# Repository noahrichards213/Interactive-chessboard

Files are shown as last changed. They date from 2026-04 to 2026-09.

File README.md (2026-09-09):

# Interactive chessboard

LED-Guided Smart Chessboard
An interactive, LED-guided smart chessboard designed for beginners. The board uses magnetic piece tracking via Hall effect sensors, provides real-time visual move guidance through an integrated LED matrix, all run by a chess engine powered by an ESP32.

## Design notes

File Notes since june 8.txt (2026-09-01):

Priority #1: get the MCP23S17 working

	ECE 231 concepts! how to calculate the current through the resistor LED combo
	0. (note cannot use OHM's law b/c diode isn't a resistor, must use datasheet current-voltage characteristic)
	1. If = (3.3 - Vf)/R, where If and Rf are forward current and forward voltage
 	2. Guess a correct point on graph
	3. According to the datasheet for the LED we are using:
	@ 1.9V, there is 7mA
        @ 1.95V, there is 15mA

	From my resistor equation:
        @ 1.9V, there is 9.3mA
	@ 1.95V, there is 9mA

	Therefore, the real operating point is somewhere between 1.9 and 1.95V and 7mA and 15mA

	So, we were outputting at most 15mA current out of each pin, 8 times per MCP, which is 5 * 15mA = 120mA < 125mA limit.

	So, it is not possible that the MCP is actually damaged from this (even w/ resistor tolerance the range we created is just too big!! There is another problem

Possible problems
1. SPI not connecting
	test: use the who am i function (use exact same code as the gyro, very very carefully read MCP datasheet for source code)
	another test: test using purposely wrongly defined pins and see if MCP.begin stil works. if it still does, then spi may not be connectinat all

June 10:

We have gotten the MCP working. Let us ponder this problem. It seems that all the hall effects have been fried because they only pull up to 0.6. I replaced one and it pulls up to 3.3.

We will need to replace other hall effects and test that (tomorrow). Today we will consider if it is even possible that hall effects were fried.

But how?

We note from the datasheet that the maximum reverse output voltage is 0.5V. We surely exceeded this when testing and trying to write 3.3V into the hall effect pin

So, we must:
- replace all 15 of the fried hall effects
- resolder the broken LED
- frankestein a 5k resistor to the square that is missing one

Then we can start testing our firmware. Start w/ same handwritten code, and then try to implement the whole thign

June 17:
After much testing, i have NO idea why the voltage only pulls up to 0.6. We have two options

- amplify the 0.6 to 3.3 so the MCP can detect it
- try a different Hall effect sensor
- use an analog to digital converter to read it

June 20:
We could use ADC multixplexers. The drawback w/ multiplexers is that we can only recognize one input at a time. Let's think about this, is this okay?

We could poll all the inputs.

Therefore, it is okay! We don't even need a new PCB because the CD74HCx4067 multiplexer takes only the following inputs:
- power
- ground
- enable
- output to an ADC pin on microcontroller
- output to select pins on microcontroller

which we can Frankenstein easily enough

Note: the multiplexer device has a maxmimum source/sink current of 25mA. How do we control for that.\
Solution: recall the functionality of the open drain device. When enough gate voltage is applied, device is shorted, no current. When not enough gate voltage is applied, current determined by pullup resistor. If we use 5kohms, then 3.3V/5kohms = 0.66mA, far less than limit

June 21:
We have ordered the multiplexers. In the meantime, we shall think about the actual final design.

I don't believe there are any suitable 8x8 matrices. So we will try to use a 5mmx5mm LED: https://www.digikey.ca/en/products/detail/quelighting-corp/QLSP08RGB-B/15848745

How will we construct the actual board around the PCB? We need to use headers to bring out hall effects, but that's it. All else should be hidden. LEDS should shine beneath the wood

We should use my glass chessboard so that LED can shine through it?

Because hall effects are kind of weak from distance. I will take the thinnest wood I can buy and make a sort of mask.

June 24:
we have successfully soldered new esp on new board. the following is the minimum we need to Frankenstein in order to test the mux:
select signal (x4)
power (attach another capacitor)
ground (attach another capacitor)
common output (can use GPIO 15, confirmed ADC)
enable signal (tied to ground)
input signal (x2)

Regular solder the hall effect, pullup resistor and decoupling capacitor

10 Frankenstein's total

June 29:
To reduce the number of Frankensteins, we will ground three of the select signals and keep one for testing different channels

The one that is not soldered to ground is s0. When s0 is ON, channel is 1, when s0 is OFF, channel is 0.

July 2:

successfully tested them mux, also retested the MCP. problem with the MCP: we will need 4 on one spi line, but all four will need to communicate at the same (light up leds). how will we accomplish this

July 2 (night):
We are trying to test two MCP's on the same SPI, right now only one of them is working.

First, let's test just the not working one to see if all the PCB connections are correct.

If that is working, then let's reconfigure the SPI. Delete the CS_pin from the argument and see what happens

July 5. 
Unfortuatnely, we can't use MCP's I realized b/c the current draw is far too much (b/c we have 16 LEDS per IC). We need some kind of LED driver

Another problem is that the MCP output just isn't working, which is super frustrating. Randomly stopped working

July 8.
So, we don't actually need the MCP. We have a design that will work for the hall effects, now we need one for the LEDS:
Let's consider the gate driver IC:

Input: weak logic signals (like from ESP 32)
Output: High current & current voltage signals

The kind of gate driver IC we will need depends on the amount of current we will need. let's consider which LED we will use

We are considering this one: JB5630AWT-P-H30GA0000-NZ000001, that is large enough and has the test current of 65mA

I'm liking the TPIC6C595 Power Logic 8-Bit Shift Register, which has:
- 8 outputs (for LEDS) (so we need 8 of them)
- one reset button (can have common for each IC)
- active low output enable
- ground
- shift register clock (can have common for each IC)
- update register clock (can have common for each IC)

Note the max ratings: Continuous drain current, each output, all outputs on, TC = 25°C is 100mA, which is well above the 65mA which will be going through the LED (note we will have compute resistor values precisely that we get the correct voltage LED, which is 2.8V

Here's the test we will perform: cascade two TCP and connect a few LEDS making sure to cover both TCPs
	
July 14.
We need a very low resistance for the LEDS.
Operating point is (2.8V, 65mA).

So, 65mA = (5 - 2.8V)/R, R is about 30 ohms

July 16.
Changing LED source to 3.3V for simplicity of PCB,
and if we choose an R of 10, operating point is at about (2.76V, 54mA), which is about 75% relative luminous flux

July 16 night
We need a switching regulator to 3.3V. So the plan is linear from 7.4 to 5 (use headers to for lipo input output), then switching from 5 to 3.3.

July 17
We need a battery with enough ampere hours, but those all have Deans T headers
We can't have a Deans T receptacle of the PCB (too much mechanical stress), so we need a Deans T to xt30 adapater(xt30 instead of jst because it has the adequate current rating)

July 19

Checking to see if LED driver will get too hot:
- assuming room temparture
- upper bound for current drawn is 60mA

Note that the allowable power dissipated is given by:(Junction temp - Ambient temp)/thermal resistance (variation of Ohm's law)

So, according to datasheet, P = (150-25)/82.3  (SOIC thermal resistance) = lower bound of 1.5 Watts.

How much power is dissipated if we have all 8 LED's on at once?
Upper bound of 60mA squared * 30ohms = 0.11W * 8 < 1 Watt

Also note: the 60mA is not being drawn from 5V because it's an open drain output, it sinks current from the LED voltage source
00
Ensuring that the buck regulator is able to provide enough current (recommended limit is 2A).
Max number of LED's on at once is 27. 60mA * 27 + 500mA for ESP < 2A.

Suppose we use 12 ohm resistor instead: then operating point is at an upper bound of 45mA via Desmos, which is about 60 percent relative luminuous flux. Okay for now

So 45mA * 27 + 500mA = 1.7A + 64 * 0.0045 (from hall effects) is just barely over 2, it's okay

Aug 30

things to add in code
-capturing (which requires changing colour each turn)
-castling
-en passant
-promotion
-weird combinations of these

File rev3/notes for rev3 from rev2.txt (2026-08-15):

July 25
- make LED footprints have more space between anode and cathode, rn it's a tough solder

August 3
- make 7.4 and GND breakouts instead of 5V and GND (into buck converter) (done
- make the breakouts female
- add switch to turn off power 

August 9
- switch not necessary, i need to take out battery to charge anyway
- female breakouts not necessary, if need be i can just solder wires to through holes

- 7.4 breakout done
- LED footprint enlarge done

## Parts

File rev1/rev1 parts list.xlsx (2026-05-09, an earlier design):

Part | # of units | Link | Notes
0.1uF cap | 3 | https://www.digikey.ca/en/products/detail/samsung-electro-mechanics/CL21B104KBCNNNC/3886661
1uF cap | 3 | https://www.digikey.ca/en/products/detail/samsung-electro-mechanics/CL21B105KBFNNNE/3886687
10nF cap | 16 | https://www.digikey.ca/en/products/detail/kyocera-avx/KGM21NR71H103KT/563493
LED | 17 | https://www.digikey.ca/en/products/detail/ams-osram-usa-inc/LS-R976-NR-1-0-20-R18/1227987
Hall effect sensor | 16 | https://www.digikey.ca/en/products/detail/melexis-technologies-nv/MLX92232LSE-AAA-002-RE/5761856
ESP prog header | 1 | https://www.digikey.ca/en/products/detail/3m/929665-09-03-I/681796
5k ohm res | 23 | https://www.digikey.ca/en/products/detail/vishay-dale/CRCW08055K00JNTA/5075662 | Power rating of 0.125W >> 3.3^2/5k = 0.002W
150 ohm res | 17 | https://www.digikey.com/en/products/detail/yageo/RC0805FR-07150RL/727613 | To calculate desired resistance; we want 10mA of current, based on LED I-V characteristic, that is at 1.8V. R = (3.3-1.8)/0.01 = 150. Also, power rating of 0.125W >> 3.3^2/150 = 0.07W
Button | 4 | https://www.digikey.ca/en/products/detail/schurter-inc/1301-9314-24/8536705
GPIO extender | 2 | https://www.digikey.ca/en/products/detail/microchip-technology/MCP23S17T-E-SO/964187
ESP 32 S3 wroom | 1 | https://www.digikey.ca/en/products/detail/espressif-systems/ESP32-S3-WROOM-1-N8/15200089 | N8 = 8 bytes of flash memory
Magnets | 16 | https://www.digikey.ca/en/products/detail/radial-magnets-inc/8195/555329 | May be too strong, but we can lift board off PCB. Should not be too weak

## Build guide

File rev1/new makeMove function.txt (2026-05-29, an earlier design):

#include "4x4makemove.h"

#include <math.h>
#include <stdio.h>

#include "4x4arraysize.h"
#include "4x4availablemoves.h"
#include "4x4castling.h"
#include "4x4enpassant.h"
#include "4x4legalinput.h"
#include "4x4legalmoveandcapture.h"
#include "4x4printing.h"
#include "4x4promotion.h"
extern Piece board[BOARDSIZE][BOARDSIZE];

//everything must go except for the actual changing of board[][]
//we also don't need to check for legal input

//we need a way to calculate board[i][j] based on array index

we need: 

int index_to_i(index){
 return index % BOARDIZE;
}

int index_to_j(index){
 return index // BOARDSIZE;
} 

//MCP_1
0: board[0][0]
1: board[1][0]
2: board[2][0]
3: board[3][0]
4: board[0][1]
5: board[1][1]
6: board[2][1]
7: board[3][1]

//MCP_2
8: board[0][2]
9: board[1][2]
10: board[2][2]
11: board[3][2]
12: board[0][3]
13: board[1][3]
14: board[2][3]
15: board[3][3]

void makeMove(int colour) {
for (int i = 0; i < BOARDSIZE * BOARDSIZE; i++){

int value = readMCP(i);
if (value != array[i]){
array[i] = value;
moveMade = executeliftedPiece(i);

//after we execurte this, there are two special possible moves
// we will assume that promotions are done by physically moving the pawn to the 8th

1. castling, we need to move the rook as well. we will hardcode all the values
if (moveMade >= 100 && moveMade < 10000){
  if (moveMade == WHITEKINGCASTLE){
    while (read_MCP(WHITE_KINGSIDE_ROOK_START) == HIGH && read_MCP(WHITE_KINGSIDE_ROOK_END) == LOW);
  }
  else if (moveMade == BLACKKINGCASTLE)
    while (read_MCP(BLACK_KINGSIDE_ROOK_START) == HIGH && read_MCP(BLACK_KINGSIDE_ROOK_END) == LOW);
  else if (moveMade == WHITEQUEENCASTLE)
    while (read_MCP(WHITE_QUEENSIDE_ROOK_START) == HIGH && read_MCP(BLACK_QUEENSIDE_ROOK_END) == LOW);
  else if (moveMade == BLACKQUEENCASTLE)
    while (read_MCP(BLACK_QUEENSIDE_ROOK_START) == HIGH && read_MCP(BLACK_QUEENSIDE_ROOK_END) == LOW);

}

2. enpassant, we need to remove the captured pawn

if (moveMade > 10000){ 
 //colour variable is from the main c program

 //if it's a white enpassant, the captured piece is +1 index from where the capturing pawn ends up
 //if it's a black en passant, the captured piece is -1 index form where the capturing pawn ends up
 int indexChange = colour == WHITE ? 1 : -1

 int removeEnPassant = moveMade / 1000;
 int calculateIndex = ((removeEnPassant % 10) * 4 + (removeEnPassant - removeEnPassant % 10)/10) + indexCahnge
 while(read_MCP(calculateIndex) == HIGH); 
}

//end of the make move function, the rest of the program's code is here
}

//implementation of liftedPiece
liftedPiece(int index){};

// how do we access register y and register x?
// based on the square we are moving to, we can calculate the index for the MCP pin

Two possible scenarios:

//we are stalling here beause there are no legal moves
if (arraySize(array[index].availableMoves == 0){
 while (readMCP(index) != 0);
} else {
 executeMovePiece(index);
}

//in each case

//implementation of executeMovePiece
int executeMovePiece(int index){};

//when a move is made, one of two things will change: the destination square will go from HIGH to LOW (capture) or LOW TO HIGH (noncapture)

//en passant, and castling are handled later
int size = arraySize(array[index].availableMoves);
int calculatedIndex;
int desiredState;
int state;
bool stop = false;
while (stop == false;){
for (int i = 0; i < size; i++){
  int moveMade = array[index].availableMoves[i];
  int x = abs(array[index].availableMoves[i]);
  if (x >= 100 & x < 10000){
    x /= 100;
  }
  
  if (x >= 10000){
    x /= 1000;
  }
  calculatedIndex = (x % 10) * 4 + (x - x % 10)/10;
  state = read_MCP(calculatedIndex);
  desiredState = array[index].availableMoves[i] ? LOW: HIGH;

  //meaning that the move wasn't a capture
  if (desiredState == HIGH){
     while(read_MCP(index) == HIGH || read_MCP(calculated_index) == LOW);
     Piece pieceMoved = board[index_to_i(index)][index_to_j(index)];
     board[index_to_i(calculatedIndex)][index_to_j(calculatedIndex)] = pieceMoved;
     board[index_to_i(index)][index_to_j(index)] = empty;

     return moveMade;
  //meaning that the move was a capture
  } else if (desiredState == LOW){
     //taking piece off
     while(read_MCP(calculatedIndex) == HIGH);
     //replace piece;
     while(read_MCP(index) == HIGH || read_MCP(calculated_index) == LOW);
     //it's okay not to do a deep copy because are setting the original pointer to NULL instantly

     Piece pieceMoved = board[index_to_i(index)][index_to_j(index)];
     board[index_to_i(calculatedIndex)][index_to_j(calculatedIndex)] = pieceMoved;
     board[index_to_i(index)][index_to_j(index)] = empty;

     return moveMade;

  }

}
}

if (we are castling){
 while (kingFrom reg and rookFrom reg FULL and kingTo reg and rookTo reg EMPTY);

  // handles castling

  // this range is just castling moves, no enpassant
  if ((yesDest >= 100 && yesDest < 10000)) {
    executeCastling(yesDest);
    return;
  }

}

if (we are promoting){
if (reg y is empty (promotion w/ no capture){
while (knightButton && bishopButton && rookButton && queenButton are all LOW);

while (reg_x is HIGH and reg_y is LOW);
if (knightButton is HIGH); 
  newPiece.type = knight;
if (bishopButton is HIGH);
  newPiece.type = bishop;
if (rookButton is HIGH);
  newPiece.type = rook;
if (queenButton is HIGH);
  newPiece.type = queen;

  create new promoted piece (code already exists in main program)
 
  if (reg y is full)
  //we need these things to happen in order:
1. reg_x goes from HIGH to LOW and reg_y goes from HIGH to LOW
while (reg_x !HIGH and reg_y !HIGH);

2. reg_y goes from LOW TO HIGH
while (reg_y !LOW);

  else if (reg y is empty)
  while (reg_x is HIGH and reg_y is EMPTY);
  MCPxpinx = newPiece
    // handles promotion 
  if (moveMade >= 10000) {
    board[BOARDSIZE - rankDest][fileDest - 97] =
        executePromotion(colour, rankDest, fileDest);
    board[BOARDSIZE - rankDest][fileDest - 97].rank = rankDest;
    board[BOARDSIZE - rankDest][fileDest - 97].file = fileDest;
    board[BOARDSIZE - rankDest][fileDest - 97].hasMoved = true;

    printf("this is the promoted type: %c\n",
           board[BOARDSIZE - rankDest][fileDest - 97].type);
    board[BOARDSIZE - rankSource][fileSource - 97] = empty;
    return;
  }

}

  // regular piece movement
  board[BOARDSIZE - rankDest][fileDest - 97] = sourcePiece;
  // but we change rank and file, set avail moves to NULL (will be chnaged later
  // but now fails loudly)
  board[BOARDSIZE - rankDest][fileDest - 97].rank = rankDest;
  board[BOARDSIZE - rankDest][fileDest - 97].file = fileDest;
  board[BOARDSIZE - rankDest][fileDest - 97].hasMoved = true;

  board[BOARDSIZE - rankSource][fileSource - 97] = empty;

  // here we remove the enemy pawn if the move is en passant (won't remove
  // regularly)

  if (yesDest >= 10000) {
    int boardDir;
    if (colour == WHITE) {
      // rank decreases as pawns move up
      boardDir = 1;
    } else if (colour == BLACK) {
      // rank increases as pawns move down
      boardDir = -1;
    }
    board[BOARDSIZE - rankDest + boardDir][fileDest - 97] = empty;
    printf("WE ARE ARRIVING HERE\n");
  }
  // here we check if we need too add en passant (kind of weird with one
  // condition in each function but whatever, can fix later)
  if (sourcePiece.type == 'P' || sourcePiece.type == 'p') {
    addEnPassant(sourcePiece, rankDest, fileDest);
  }
  return;
}

  // remove en passant moves if they weren't aleady made
  removeEnPassant();

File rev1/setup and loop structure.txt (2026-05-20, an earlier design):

// including necessary default libraries
#include <ctype.h>
#include <math.h>
#include <stdbool.h>
#include <stdio.h>
#include <stdlib.h>
#include <string.h>

// including header files

// USEFUL FUNCTIONS

// arraysize
#include "4x4arraysize.h"

// check one dir
#include "4x4checkonedir.h"

// availablemoves
#include "4x4availablemoves.h"

// END OF USEFUL FUNCTIONS

// constants and piece data structure
#include "4x4constantsandstructs.h"

// functions for all legal moves
#include "4x4availablemoves.h"

// global board
Piece board[BOARDSIZE][BOARDSIZE];

// setup
#include "4x4setup.h"

// make move
#include "4x4makemove.h"

// printing things to console
#include "4x4printing.h"

// checking functions
#include "4x4checking.h"

// include legal move and capture functions
#include "4x4legalmoveandcapture.h"

// include en passant mechanics
#include "4x4enpassant.h"

// include function to remove illegal moves because it would leave player in
// check
#include "4x4removecheck.h"

void setup()
  // setting up board & list of pieces
  blankSquares();
  testPawn();

  int colour = WHITE;

  for (int i = 0; i < BOARDSIZE; i++) {
    for (int j = 0; j < BOARDSIZE; j++) {
      if (board[i][j].type != '_') {
        changeAvailableMoves(&board[i][j]);
      }
    }
  }

// to handle mechanics of picking up and placing down pieces

//setup board (e.g rank 1, 2, 7, 8 being detected by hall effect, the others not)
//map board[][] pieces to registers on the MCP, put all of MCPxpinx in array for *ordered* access

e.g volatile Piece MCP1pin1 = board[1][1];
e.g volatile Piece MCP1pin2 = board[0][1];
e.g volatile Piece MCP1pin3 = empty;

//NOTE: HOW DOES READING WORK FOR MCP, IF WE HAVE MULTIPLE OF THEM
we initialize an MCP object by defining CS, MOSI, MISO, CLK pins
then we call MCP_object.read1(pin#) // pin numbers are between 0 and 16

//NOTE: HOW DOES WRITING WORK FOR MCP, IF WE HAVE MULTIPLE OF THEM
we initialize an MCP object by defining CS, MOSI, MISO, and CLK pins, then we 
call MCP_object.write1(pin#, value). the value is literally 1 for high or 0 for low

//HOW ARE WE GOING TO PUT THE AVAILABLE MOVES INTO THE MCPPIN ARRAY? answer: each element in the array is a Piece object w/ the available moves array
#define WHITE KINGSIDE ROOK START 15 
#define WHITE KINGSIDE ROOK END 7
#define BLACK KINGSIDE ROOK START 12 
#define BLACK KINGSIDE ROOK END 4

#define WHITE QUEENSIDE ROOK START 3
#define WHITE QUEENSIDE ROOK END 11
#define BLACK QUEENSIDE ROOK START 0 
#define BLACK QUEENSIDE ROOK END 8

//CALCULATION FOR THE 4X4 BOARD, HOW ARE THE PIECES GOING TO BE ORDERED
index number on the left

//MCP_1
0: board[0][0]
1: board[1][0]
2: board[2][0]
3: board[3][0]
4: board[0][1]
5: board[1][1]
6: board[2][1]
7: board[3][1]

//MCP_2
8: board[0][2]
9: board[1][2]
10: board[2][2]
11: board[3][2]
12: board[0][3]
13: board[1][3]
14: board[2][3]
15: board[3][3]

//read function b/c we have two MCP's

int read_MCP(int index){
if (index < 8){
 return MCP_1.read1(i);
} else if (index > 8){
 return MCP_2.read1(i - 8);
}

}

void loop()

  //need to rewrite haveMove to include the MCP stuff rather than tet
  bool haveMove = true;

  // print initial board and legal moves
  printBoard();
  printLegalMoves();

  // if there is a legal move to be made
  while (haveMove) {
    makeMove(colour);

    if (colour == WHITE) {
      colour = BLACK;
    } else if (colour == BLACK) {
      colour = WHITE;
    }

    // change legal moves
    for (int i = 0; i < BOARDSIZE; i++) {
      for (int j = 0; j < BOARDSIZE; j++) {
        if (board[i][j].type != '_') {
          changeAvailableMoves(&board[i][j]);
        }
      }
    }

    for (int i = 0; i < BOARDSIZE; i++) {
      for (int j = 0; j < BOARDSIZE; j++) {
        // first, we need to check every single move and see if it leads to
        // check (it then would be unallowed)
        if (board[i][j].colour == colour) {
          for (int k = 0; k < arraySize(board[i][j].availableMoves); k++) {
            if (removeCheck(board[i][j], k, board[i][j].availableMoves[k]) ==
                true) {
              board[i][j].availableMoves[k] = ALLOWSCHECK;
            }
          }
        }
      }
    }

    printLegalMoves();
    printBoard();

    haveMove = checkLegalMoves(colour);
  }

  if (inCheck(colour)) {
    printf("It's checkmate\n");
  } else {
    printf("It's stalemate\n");
  }

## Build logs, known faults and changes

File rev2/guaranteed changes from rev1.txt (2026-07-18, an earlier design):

May 29 2026
- still need to test if the hall effect/ gpio extender/ led idea is going to work

- guaranteed changes: different LED's: like this one: JB5630AWT-P-H30GA0000-NZ000001

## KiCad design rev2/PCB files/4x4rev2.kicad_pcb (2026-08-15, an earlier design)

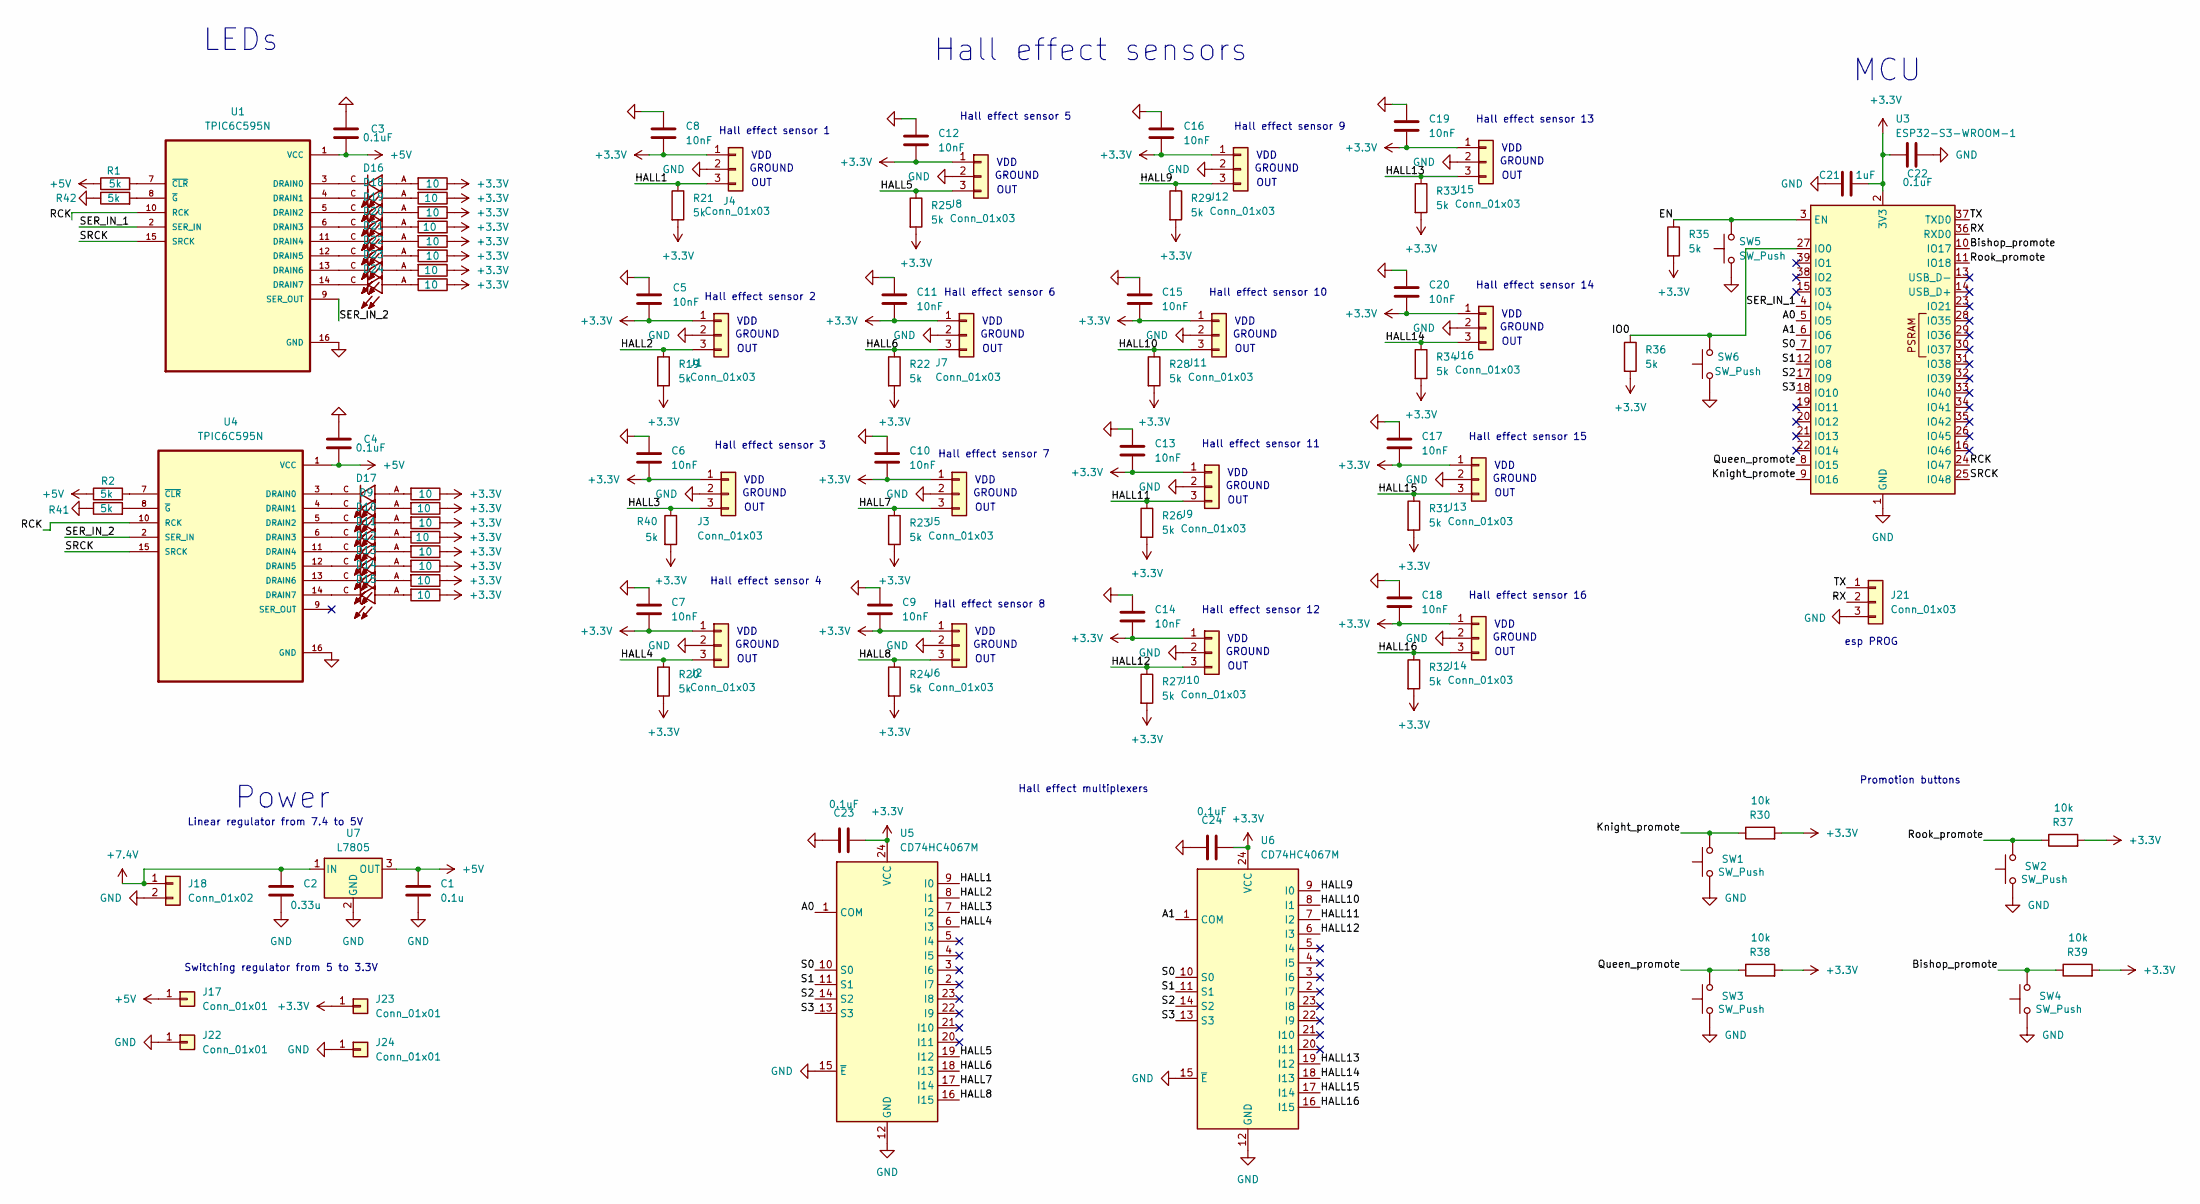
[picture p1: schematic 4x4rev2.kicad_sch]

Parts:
C1: 0.1u; C_0805_2012Metric
C2: 0.33u; C_0805_2012Metric
C3, C4, C22, C23, C24: 0.1uF; C_0805_2012Metric
C5, C6, C7, C8, C9, C10, C11, C12, C13, C14, C15, C16, C17, C18, C19, C20: 10nF; C_0805_2012Metric
C21: 1uF; C_0805_2012Metric
D9, D10, D11, D12, D13, D14, D15, D16, D17, D18, D19, D20, D21, D22, D23, D24: JB5630AWT-P-H40GA0000-NZ000001; LED_JB5630AWT-P-H40GA0000-NZ000001; PARTREV 3
J1, J2, J3, J4, J5, J6, J7, J8, J9, J10, J11, J12, J13, J14, J15, J16: Conn_01x03; TSOT-3L_MLX92232LSE-AAA-002-SP_MEL
J17, J22, J23, J24: Conn_01x01; PinHeader_1x01_P2.54mm_Vertical
J18: Conn_01x02; AMASS_XT30U-M_1x02_P5.0mm_Vertical
J21: Conn_01x03; PinHeader_1x03_P2.54mm_Vertical
R1, R2, R19, R20, R21, R22, R23, R24, R25, R26, R27, R28, R29, R31, R32, R33, R34, R35, R36, R40, R41, R42: 5k; R_0805_2012Metric_Pad1.20x1.40mm_HandSolder
R3, R4, R5, R6, R7, R8, R9, R10, R11, R12, R13, R14, R15, R16, R17, R18: 10; R_0805_2012Metric_Pad1.20x1.40mm_HandSolder
R30, R37, R38, R39: 10k; R_0805_2012Metric_Pad1.20x1.40mm_HandSolder
SW1, SW2, SW3, SW4, SW5, SW6: SW_Push; SW_SPST_SKQG_WithStem
U1, U4: TPIC6C595N; SOIC127P600X175-16N
U3: ESP32-S3-WROOM-1
U5, U6: CD74HC4067M; SOIC127P1030X265-24N
U7: L7805; L7805CDTTR

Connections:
+3.3V: C5.2, C6.2, C7.2, C8.2, C9.2, C10.2, C11.2, C12.2, C13.2, C14.2, C15.2, C16.2, C17.2, C18.2, C19.2, C20.2, C21.2, C22.2, C23.2, C24.2, J1.1, J2.1, J3.1, J4.1, J5.1, J6.1, J7.1, J8.1, J9.1, J10.1, J11.1, J12.1, J13.1, J14.1, J15.1, J16.1, J23.1, R3.1, R4.1, R5.1, R6.1, R7.1, R8.1, R9.1, R10.1, R11.1, R12.1, R13.1, R14.1, R15.1, R16.1, R17.1, R18.1, R19.2, R20.2, R21.2, R22.2, R23.2, R24.2, R25.2, R26.2, R27.2, R28.2, R29.2, R30.2, R31.2, R32.2, R33.2, R34.2, R35.2, R36.2, R37.2, R38.2, R39.2, R40.2, U3.2 (3V3), U5.24 (VCC), U6.24 (VCC)
+5V: C1.1, C3.2, C4.2, J17.1, R1.1, R2.1, U1.1 (VCC), U4.1 (VCC), U7.3 (OUT)
+7.4V: C2.1, J18.1, U7.1 (IN)
/A0: U3.5 (IO5), U5.1 (COM)
/A1: U3.6 (IO6), U6.1 (COM)
/Bishop_promote: R39.1, SW4.2, U3.10 (IO17)
/EN: R35.1, SW5.2, U3.3 (EN)
/HALL1: J4.3, R21.1, U5.9 (I0)
/HALL2: J1.3, R19.1, U5.8 (I1)
/HALL3: J3.3, R40.1, U5.7 (I2)
/HALL4: J2.3, R20.1, U5.6 (I3)
/HALL5: J8.3, R25.1, U5.19 (I12)
/HALL6: J7.3, R22.1, U5.18 (I13)
/HALL7: J5.3, R23.1, U5.17 (I14)
/HALL8: J6.3, R24.1, U5.16 (I15)
/HALL9: J12.3, R29.1, U6.9 (I0)
/HALL10: J11.3, R28.1, U6.8 (I1)
/HALL11: J9.3, R26.1, U6.7 (I2)
/HALL12: J10.3, R27.1, U6.6 (I3)
/HALL13: J15.3, R33.1, U6.19 (I12)
/HALL14: J16.3, R34.1, U6.18 (I13)
/HALL15: J13.3, R31.1, U6.17 (I14)
/HALL16: J14.3, R32.1, U6.16 (I15)
/IO0: R36.1, SW6.2, U3.27 (IO0)
/Knight_promote: R30.1, SW1.2, U3.9 (IO16)
/Queen_promote: R38.1, SW3.2, U3.8 (IO15)
/RCK: U1.10 (RCK), U3.24 (IO47), U4.10 (RCK)
/RX: J21.2, U3.36 (RXD0)
/Rook_promote: R37.1, SW2.2, U3.11 (IO18)
/S0: U3.7 (IO7), U5.10 (S0), U6.10 (S0)
/S1: U3.12 (IO8), U5.11 (S1), U6.11 (S1)
/S2: U3.17 (IO9), U5.14 (S2), U6.14 (S2)
/S3: U3.18 (IO10), U5.13 (S3), U6.13 (S3)
/SER_IN_1: U1.2 (SER_IN), U3.4 (IO4)
/SER_IN_2: U1.9 (SER_OUT), U4.2 (SER_IN)
/SRCK: U1.15 (SRCK), U3.25 (IO48), U4.15 (SRCK)
/TX: J21.1, U3.37 (TXD0)
GND: C1.2, C2.2, C3.1, C4.1, C5.1, C6.1, C7.1, C8.1, C9.1, C10.1, C11.1, C12.1, C13.1, C14.1, C15.1, C16.1, C17.1, C18.1, C19.1, C20.1, C21.1, C22.1, C23.1, C24.1, J1.2, J2.2, J3.2, J4.2, J5.2, J6.2, J7.2, J8.2, J9.2, J10.2, J11.2, J12.2, J13.2, J14.2, J15.2, J16.2, J18.2, J21.3, J22.1, J24.1, R41.1, R42.1, SW1.1, SW2.1, SW3.1, SW4.1, SW5.1, SW6.1, U1.16 (GND), U3.1 (GND), U3.40 (GND), U3.41 (GND), U4.16 (GND), U5.12 (GND), U5.15 (~E), U6.12 (GND), U6.15 (~E), U7.2 (GND)
unnamed: D9.A, R12.2
unnamed: D10.A, R13.2
unnamed: D11.A, R14.2
unnamed: D12.A, R15.2
unnamed: D13.A, R16.2
unnamed: D14.A, R17.2
unnamed: D15.A, R18.2
unnamed: D16.A, R3.2
unnamed: D17.A, R11.2
unnamed: D18.A, R4.2
unnamed: D19.A, R5.2
unnamed: D20.A, R6.2
unnamed: D21.A, R7.2
unnamed: D22.A, R8.2
unnamed: D23.A, R9.2
unnamed: D24.A, R10.2
unnamed: D16.C, U1.3 (DRAIN0)
unnamed: D18.C, U1.4 (DRAIN1)
unnamed: D19.C, U1.5 (DRAIN2)
unnamed: D20.C, U1.6 (DRAIN3)
unnamed: D21.C, U1.11 (DRAIN4)
unnamed: D22.C, U1.12 (DRAIN5)
unnamed: D23.C, U1.13 (DRAIN6)
unnamed: D24.C, U1.14 (DRAIN7)
unnamed: R1.2, U1.7 (~CLR)
unnamed: R42.2, U1.8 (~G)
unnamed: D17.C, U4.3 (DRAIN0)
unnamed: D9.C, U4.4 (DRAIN1)
unnamed: D10.C, U4.5 (DRAIN2)
unnamed: D11.C, U4.6 (DRAIN3)
unnamed: D12.C, U4.11 (DRAIN4)
unnamed: D13.C, U4.12 (DRAIN5)
unnamed: D14.C, U4.13 (DRAIN6)
unnamed: D15.C, U4.14 (DRAIN7)
unnamed: R2.2, U4.7 (~CLR)
unnamed: R41.2, U4.8 (~G)

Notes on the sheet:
OUT
esp PROG
GROUND
VDD
Hall effect sensor 10
Hall effect sensor 9
Power
Hall effect sensor 15
Hall effect sensor 1
Promotion buttons
Hall effect sensor 14
Hall effect sensor 5
Hall effect sensor 16
Hall effect sensor 2
Hall effect sensor 3
LEDs
Hall effect sensor 8
Hall effect multiplexers
Hall effect sensor 11
Linear regulator from 7.4 to 5V
Switching regulator from 5 to 3.3V
MCU
Hall effect sensor 4
Hall effect sensor 7
Hall effect sensors
Hall effect sensor 13
Hall effect sensor 12
Hall effect sensor 6

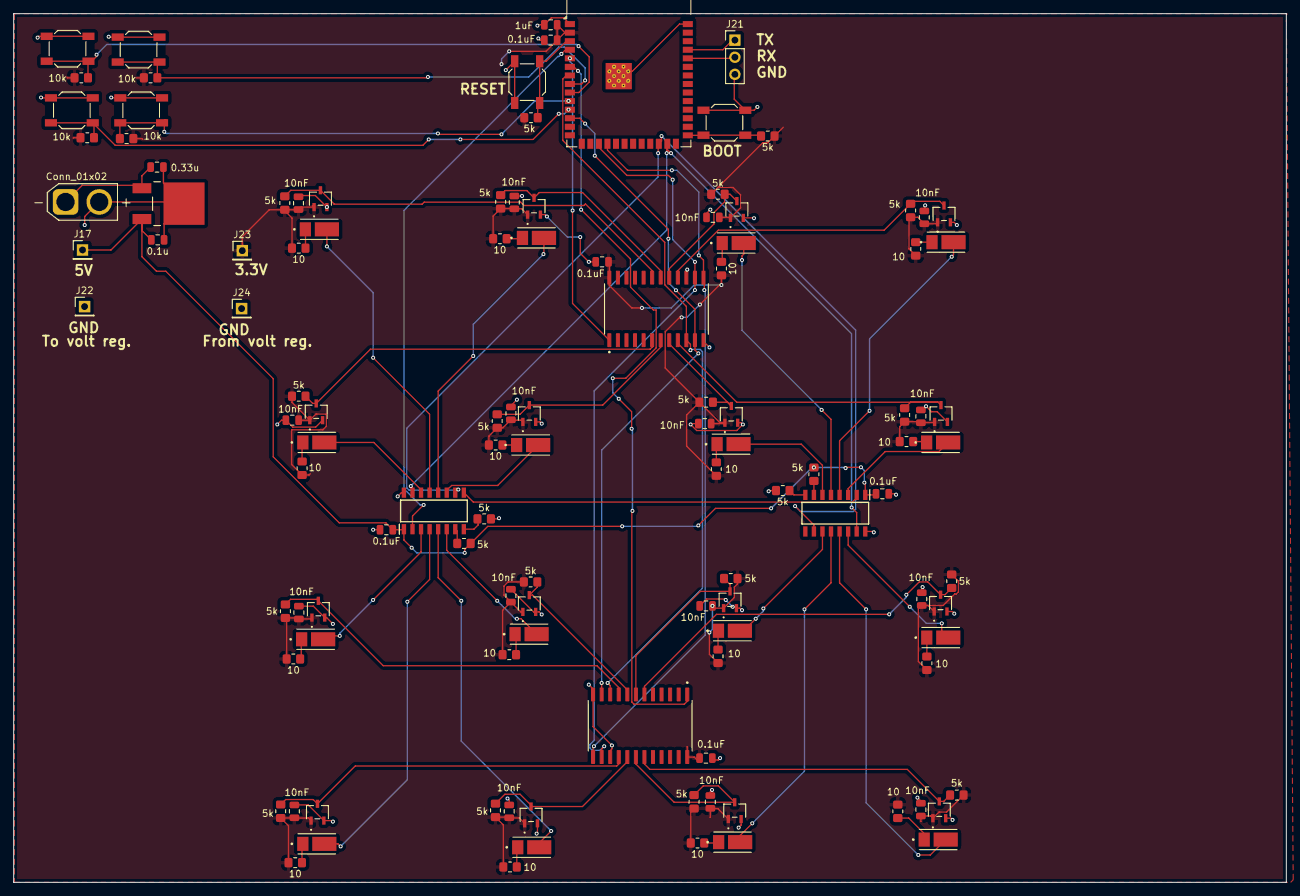
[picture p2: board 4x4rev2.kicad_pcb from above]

Board: 2 copper layers, 188.8 x 128.9 mm, 116 parts (0 on the bottom side), 74 nets.

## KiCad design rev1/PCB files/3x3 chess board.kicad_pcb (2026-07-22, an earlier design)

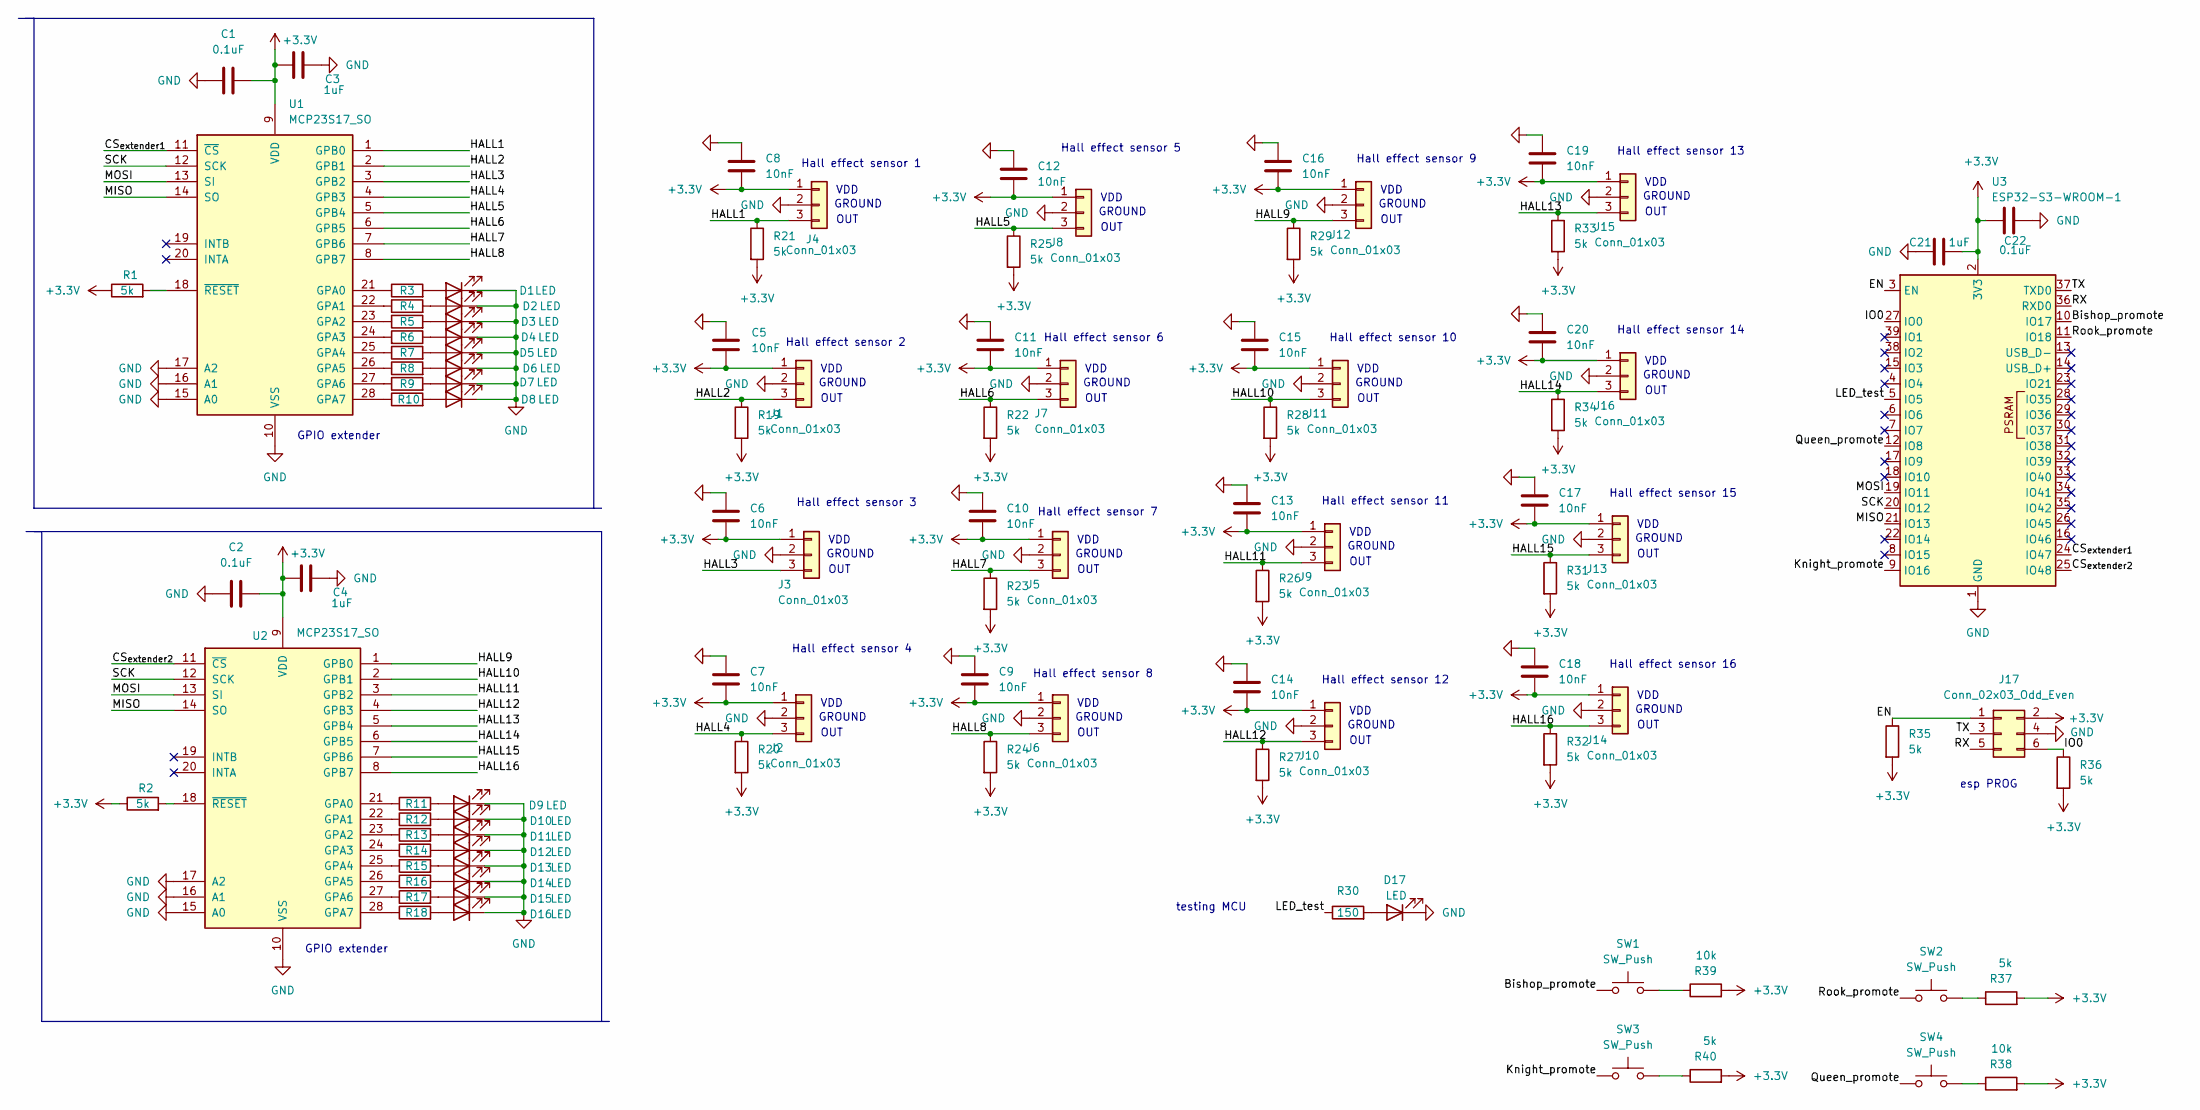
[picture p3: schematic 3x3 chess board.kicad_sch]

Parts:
C1, C2, C22: 0.1uF; C_0805_2012Metric
C3, C4, C21: 1uF; C_0805_2012Metric
C5, C6, C7, C8, C9, C10, C11, C12, C13, C14, C15, C16, C17, C18, C19, C20: 10nF; C_0805_2012Metric
D1, D2, D3, D4, D5, D6, D7, D8, D9, D10, D11, D12, D13, D14, D15, D16, D17: LED; D_0805_2012Metric_Pad1.15x1.40mm_HandSolder
J1, J2, J3, J4, J5, J6, J7, J8, J9, J10, J11, J12, J13, J14, J15, J16: Conn_01x03; TSOT-3L_MLX92232LSE-AAA-002-SP_MEL
J17: Conn_02x03_Odd_Even; IDC-Header_2x03_P2.54mm_Vertical
R1, R2, R19, R20, R21, R22, R23, R24, R25, R26, R27, R28, R29, R31, R32, R33, R34, R35, R36, R37, R40: 5k; R_0805_2012Metric_Pad1.20x1.40mm_HandSolder
R3, R4, R5, R6, R7, R8, R9, R10, R11, R12, R13, R14, R15, R16, R17, R18, R30: 150; R_0805_2012Metric_Pad1.20x1.40mm_HandSolder
R38, R39: 10k; R_0805_2012Metric_Pad1.20x1.40mm_HandSolder
SW1, SW2, SW3, SW4: SW_Push; SW_PUSH_6mm_H4.3mm
U1, U2: MCP23S17_SO; SOIC-28W_7.5x17.9mm_P1.27mm
U3: ESP32-S3-WROOM-1

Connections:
+3.3V: C1.2, C2.2, C3.2, C4.2, C5.2, C6.2, C7.2, C8.2, C9.2, C10.2, C11.2, C12.2, C13.2, C14.2, C15.2, C16.2, C17.2, C18.2, C19.2, C20.2, C21.2, C22.2, J1.1, J2.1, J3.1, J4.1, J5.1, J6.1, J7.1, J8.1, J9.1, J10.1, J11.1, J12.1, J13.1, J14.1, J15.1, J16.1, J17.2, R1.1, R2.1, R19.2, R20.2, R21.2, R22.2, R23.2, R24.2, R25.2, R26.2, R27.2, R28.2, R29.2, R31.2, R32.2, R33.2, R34.2, R35.2, R36.2, R37.2, R38.2, R39.2, R40.2, U1.9 (VDD), U2.9 (VDD), U3.2 (3V3)
/Bishop_promote: SW1.1, U3.10 (IO17)
/CS_{extender1}: U1.11 (~CS), U3.24 (IO47)
/CS_{extender2}: U2.11 (~CS), U3.25 (IO48)
/EN: J17.1, R35.1, U3.3 (EN)
/HALL1: J4.3, R21.1, U1.1 (GPB0)
/HALL2: J1.3, R19.1, U1.2 (GPB1)
/HALL3: J3.3, U1.3 (GPB2)
/HALL4: J2.3, R20.1, U1.4 (GPB3)
/HALL5: J8.3, R25.1, U1.5 (GPB4)
/HALL6: J7.3, R22.1, U1.6 (GPB5)
/HALL7: J5.3, R23.1, U1.7 (GPB6)
/HALL8: J6.3, R24.1, U1.8 (GPB7)
/HALL9: J12.3, R29.1, U2.1 (GPB0)
/HALL10: J11.3, R28.1, U2.2 (GPB1)
/HALL11: J9.3, R26.1, U2.3 (GPB2)
/HALL12: J10.3, R27.1, U2.4 (GPB3)
/HALL13: J15.3, R33.1, U2.5 (GPB4)
/HALL14: J16.3, R34.1, U2.6 (GPB5)
/HALL15: J13.3, R31.1, U2.7 (GPB6)
/HALL16: J14.3, R32.1, U2.8 (GPB7)
/IO0: J17.6, R36.1, U3.27 (IO0)
/Knight_promote: SW3.1, U3.9 (IO16)
/LED_test: R30.1, U3.5 (IO5)
/MISO: U1.14 (SO), U2.14 (SO), U3.21 (IO13)
/MOSI: U1.13 (SI), U2.13 (SI), U3.19 (IO11)
/Queen_promote: SW4.1, U3.12 (IO8)
/RX: J17.5, U3.36 (RXD0)
/Rook_promote: SW2.1, U3.11 (IO18)
/SCK: U1.12 (SCK), U2.12 (SCK), U3.20 (IO12)
/TX: J17.3, U3.37 (TXD0)
GND: C1.1, C2.1, C3.1, C4.1, C5.1, C6.1, C7.1, C8.1, C9.1, C10.1, C11.1, C12.1, C13.1, C14.1, C15.1, C16.1, C17.1, C18.1, C19.1, C20.1, C21.1, C22.1, D1.1 (K), D2.1 (K), D3.1 (K), D4.1 (K), D5.1 (K), D6.1 (K), D7.1 (K), D8.1 (K), D9.1 (K), D10.1 (K), D11.1 (K), D12.1 (K), D13.1 (K), D14.1 (K), D15.1 (K), D16.1 (K), D17.1 (K), J1.2, J2.2, J3.2, J4.2, J5.2, J6.2, J7.2, J8.2, J9.2, J10.2, J11.2, J12.2, J13.2, J14.2, J15.2, J16.2, J17.4, U1.10 (VSS), U1.15 (A0), U1.16 (A1), U1.17 (A2), U2.10 (VSS), U2.15 (A0), U2.16 (A1), U2.17 (A2), U3.1 (GND), U3.40 (GND), U3.41 (GND)
unnamed: D1.2 (A), R3.2
unnamed: D2.2 (A), R4.2
unnamed: D3.2 (A), R5.2
unnamed: D4.2 (A), R6.1
unnamed: D5.2 (A), R7.2
unnamed: D6.2 (A), R8.2
unnamed: D7.2 (A), R9.2
unnamed: D8.2 (A), R10.2
unnamed: D9.2 (A), R11.2
unnamed: D10.2 (A), R12.2
unnamed: D11.2 (A), R13.2
unnamed: D12.2 (A), R14.2
unnamed: D13.2 (A), R15.2
unnamed: D14.2 (A), R16.2
unnamed: D15.2 (A), R17.2
unnamed: D16.2 (A), R18.2
unnamed: D17.2 (A), R30.2
unnamed: R37.1, SW2.2
unnamed: R38.1, SW4.2
unnamed: R39.1, SW1.2
unnamed: R40.1, SW3.2
unnamed: R3.1, U1.21 (GPA0)
unnamed: R4.1, U1.22 (GPA1)
unnamed: R5.1, U1.23 (GPA2)
unnamed: R6.2, U1.24 (GPA3)
unnamed: R7.1, U1.25 (GPA4)
unnamed: R8.1, U1.26 (GPA5)
unnamed: R9.1, U1.27 (GPA6)
unnamed: R10.1, U1.28 (GPA7)
unnamed: R1.2, U1.18 (~RESET)
unnamed: R11.1, U2.21 (GPA0)
unnamed: R12.1, U2.22 (GPA1)
unnamed: R13.1, U2.23 (GPA2)
unnamed: R14.1, U2.24 (GPA3)
unnamed: R15.1, U2.25 (GPA4)
unnamed: R16.1, U2.26 (GPA5)
unnamed: R17.1, U2.27 (GPA6)
unnamed: R18.1, U2.28 (GPA7)
unnamed: R2.2, U2.18 (~RESET)

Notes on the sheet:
GROUND
testing MCU
VDD
Hall effect sensor 6
OUT
GPIO extender
Hall effect sensor 7
Hall effect sensor 15
Hall effect sensor 5
Hall effect sensor 10
esp PROG
Hall effect sensor 13
Hall effect sensor 11
Hall effect sensor 14
Hall effect sensor 16
Hall effect sensor 12
Hall effect sensor 3
Hall effect sensor 1
Hall effect sensor 9
Hall effect sensor 4
Hall effect sensor 8
Hall effect sensor 2

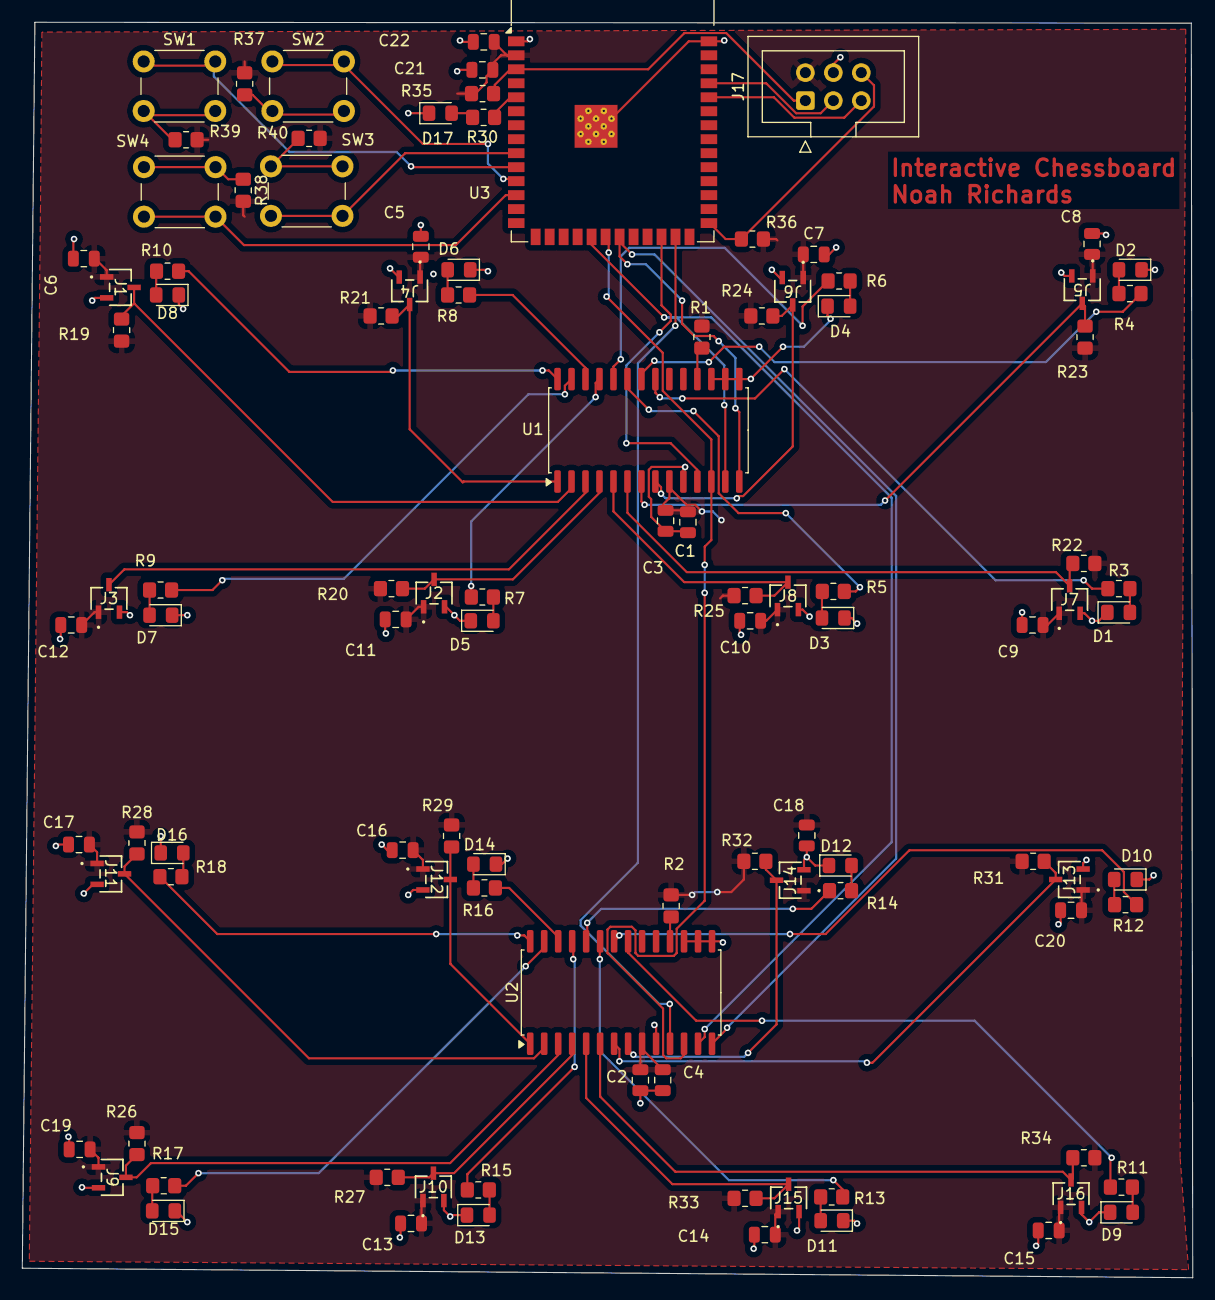
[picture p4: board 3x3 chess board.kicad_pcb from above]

Board: 2 copper layers, 106.3 x 114.0 mm, 103 parts (0 on the bottom side), 71 nets.

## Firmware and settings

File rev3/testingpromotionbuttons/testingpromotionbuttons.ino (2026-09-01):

// Define the range of GPIO pins to poll
const int startPin = 15;
const int endPin = 18;

void setup() {
  // Start serial communication at 9600 baud
  Serial.begin(115200);
  
  // Configure pins 15 to 18 as inputs with internal pull-ups
  // (Change to INPUT if you are using external pull-down resistors)
  for (int pin = startPin; pin <= endPin; pin++) {
    pinMode(pin, INPUT_PULLUP);
  }
}

void loop() {
  // Loop through each pin and check its state
  for (int pin = startPin; pin <= endPin; pin++) {
    int pinState = digitalRead(pin);
    
    // If the pin is pulled LOW, print an alert
    if (pinState == LOW) {
      Serial.print("Alert: Pin ");
      Serial.print(pin);
      Serial.println(" is LOW!");
    }
  }
  
  // Short delay to avoid spamming the Serial Monitor
  delay(100);
}

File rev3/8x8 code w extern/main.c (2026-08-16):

// including necessary default libraries
#include <stdbool.h>
#include <stdio.h>

// including header files

// USEFUL FUNCTIONS

// arraysize
#include "arraysize.h"

// check one dir
#include "checkonedir.h"

// availablemoves
#include "availablemoves.h"

// constants and piece data structure
#include "constantsandstructs.h"

// functions for all legal moves
#include "availablemoves.h"

// global board
Piece board[8][8];

// setup
#include "setup.h"

// make move
#include "makemove.h"

// printing things to console
#include "printing.h"

// checking functions
#include "checking.h"

// include legal move and capture functions
#include "legalmoveandcapture.h"

// include en passant mechanics
#include "enpassant.h"

// function to remove illegal moves because it would leave player in check
#include "removecheck.h"

int main() {
  // setting up board & list of pieces
  setupfunction();

  printf("We are setting up before crashing\n");

  int colour = WHITE;
  bool haveMove = true;

  // print initial board and legal moves
  printBoard(board);
  printLegalMoves();

  // if there is a legal move to be made
  while (haveMove) {
    makeMove(colour);

    // change legal moves
    for (int i = 0; i < 8; i++) {
      for (int j = 0; j < 8; j++) {
        if (board[i][j].type != '_') {
          changeAvailableMoves(&board[i][j], colour);
        }
      }
    }

    for (int i = 0; i < 8; i++) {
      for (int j = 0; j < 8; j++) {
        // first, we need to check every single move and see if it leads to
        // check (it then would be unallowed)
        int size = arraySize(board[i][j].availableMoves);
        for (int k = 0; k < size; k++) {
          if (board[i][j].type != '_') {
            if (removeCheck(board[i][j], k, board[i][j].availableMoves[k]) ==
                true) {
              if (board[i][j].type == 'n') {
                printf("The piece was: %c\n", board[i][j].type);
                printf("These are its legal moves:\n");
                for (int p = 0; p < arraySize(board[i][j].availableMoves);
                     p++) {
                  printf("%d", board[i][j].availableMoves[p]);
                }
              }
              board[i][j].availableMoves[k] = ALLOWSCHECK;
            }
          }
        }
      }
    }
    printLegalMoves();
    printBoard(board);

    if (colour == WHITE) {
      colour = BLACK;
    } else if (colour == BLACK) {
      colour = WHITE;
    }
    haveMove = checkLegalMoves(colour);
  }

  if (inCheck(colour)) {
    printf("It's checkmate\n");
  } else {
    printf("It's stalemate\n");
  }

  return 0;
}

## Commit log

2026-03-08 adding kicad files
    [3x3 chess board.kicad_pcb, 3x3 chess board.kicad_sch]
2026-03-08 Create PCB files
2026-03-08 adding PCB files to folder
    [3x3 chess board.kicad_pcb, 3x3 chess board.kicad_sch]
2026-04-02 update schematic and and pcb w/ new mcu
    [3x3 chess board.kicad_pcb, 3x3 chess board.kicad_sch]
2026-05-05 Changes
    - updated PCB
    - now pieces can't move such that check is allowed
    [3x3 chess board.kicad_pcb]
2026-05-05 changes
    added promotion buttons, removed interrupts, cleaned up silkscreen
    [3x3 chess board.kicad_pcb, 3x3 chess board.kicad_sch]
2026-05-07 changes
    fixed promotion, verfiied castling, now working on en passant
    [main.c]
2026-05-07 changes
    successfully created en passant, fixed castling
    [main.c]
2026-05-09 DONE
    fixed yesterday's problem, as far as I am aware, FULLY OPERATIONAL CHESS GAME
    [main.c]
2026-05-09 adjustments before ordering
    udpated res values, added gerber files and parts list files
    [3x3 chess board.kicad_pcb, 3x3 chess board.kicad_sch, rev1 parts list.xlsx]
2026-05-09 added 4x4 board
    next step: edit 4x4 board to be ready for testing
    [rev1 parts list.xlsx]
2026-06-10 changes
    notes about plan for week of june 8
    [3x3 chess board.kicad_pcb]
2026-06-25 fixing file bugs
    fixing file bugs
    [Multiplexer_code.ino]
2026-07-18 update
    update
    [4x4rev2.kicad_pcb, 4x4rev2.kicad_sch, 8x8 chessboard.kicad_pcb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]
2026-07-20 rev2 done
    rev2 done
    [4x4rev2-B_Cu.gbr, 4x4rev2-B_Mask.gbr, 4x4rev2-B_Paste.gbr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]
2026-07-22 updated pseudocode ready for test
    updated pseudocode ready for test
    [3x3 chess board.kicad_pcb, 3x3 chess board.kicad_sch, 4x4rev2.kicad_pcb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]
2026-09-01 almost done just some bugs
    almost done just some bugs
    [test_written_before_8x8_arrived.ino, testingpromotionbuttons.ino]
